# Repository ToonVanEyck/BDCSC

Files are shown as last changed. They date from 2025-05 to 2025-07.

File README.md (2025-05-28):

# Brushed DC Motor Servo Control

The goal of this project is to achieve precise control of a brushed DC motor using sensor less position control based on ripple counting.

# Relevant Application Notes
- [Microchip [AN3049]](https://ww1.microchip.com/downloads/en/AppNotes/Sensorless-Position-Control-of-Brushed-DC-Motor-Using-Ripple-Counting-Technique-00003049A.pdf)
- [TI [TIDA-01421]](https://www.ti.com/lit/ug/tidud30a/tidud30a.pdf?ts=1748200754762)

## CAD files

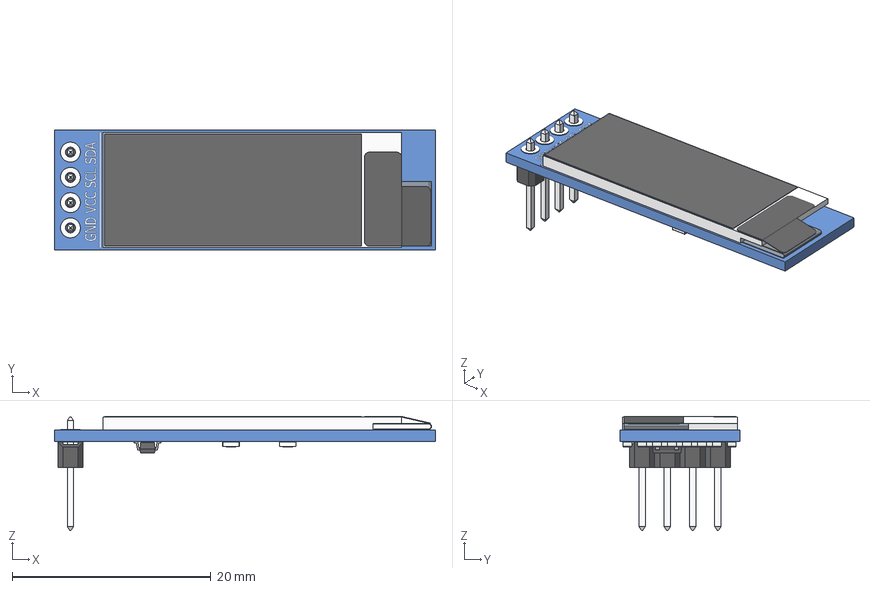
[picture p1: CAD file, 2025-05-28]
hardware/resources/OLED_0.91_128x32.stp
38.3 x 12.1 x 11.5 mm
OLED_0.91_128x32
Pin Header 4 x 1 TH 2.54mm Pitch
RESC-0603 x 13
2SD0601A

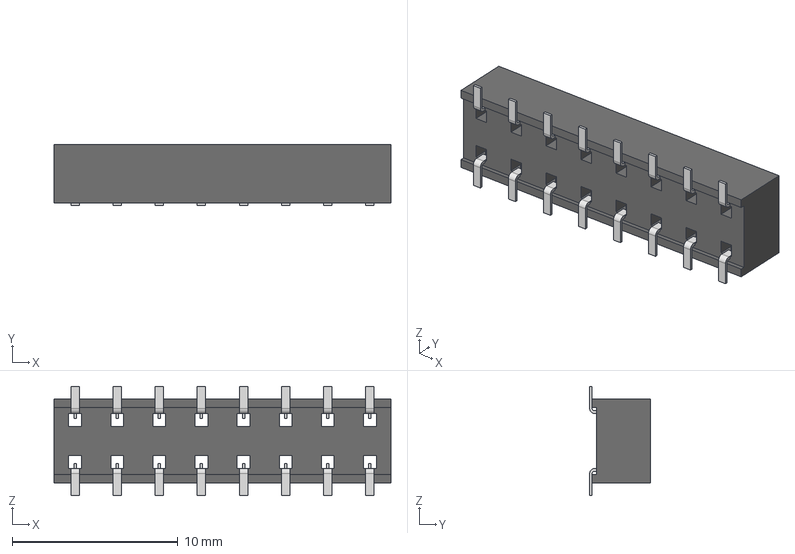
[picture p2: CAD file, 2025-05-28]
hardware/resources/HLE-108-02-L-DV-BE-TR.stp
20.3 x 3.66 x 6.58 mm
HLE-108-02-DV_socket
C-132-12-08-L-DV
C-132-12-08-F-DV2

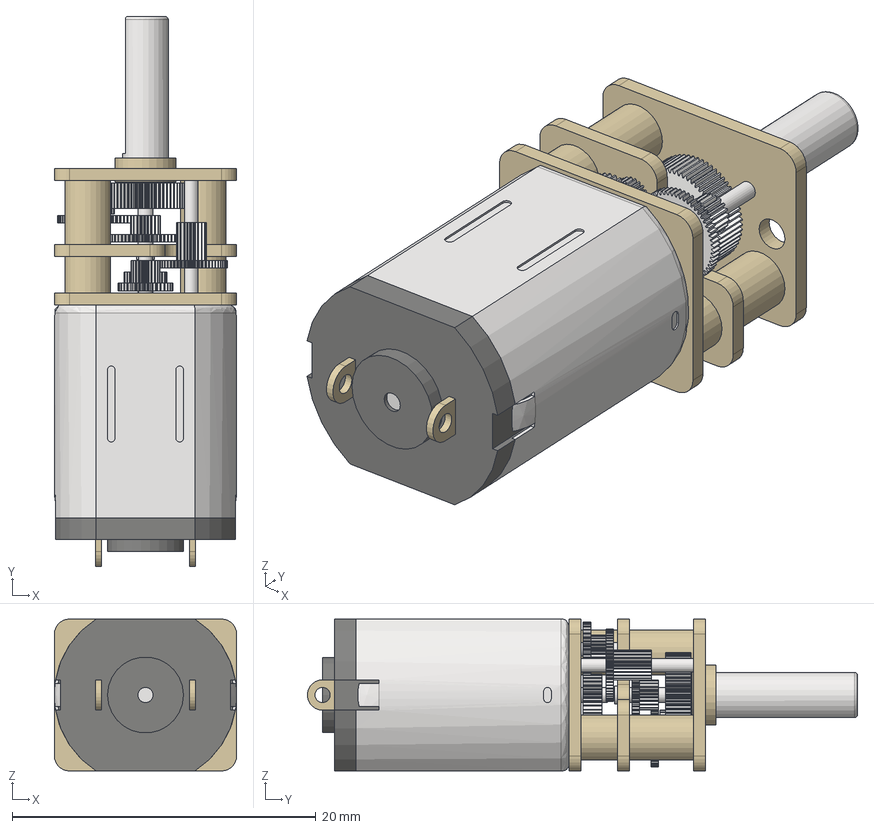
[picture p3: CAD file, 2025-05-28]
hardware/resources/GA12-N20.stp
12.0 x 36.2 x 10.0 mm
Base
Rotor
Apoio Contato
Contato
Suporte Contato
Imãs
Terminais x 2
Escovas
Chapa Inferior
Chapa Intermediária
Chapa Superior
Eixo Maior - Engrenagem
Eixo Menor - Engrenagem
Parafuso x 2
Suporte Bobinas
Eixo Menor - Engrenagem_1
Engrenagem reta1
Engrenagem reta2
Engrenagem reta1_1
Engrenagem reta2_1
Eixo - Encaixe D
Engrenagem reta1_2
Engrenagem reta2_2
Engrenagem reta1_3
Engrenagem reta2_3
Engrenagem reta1_4
Engrenagem reta2_4
Carcaça

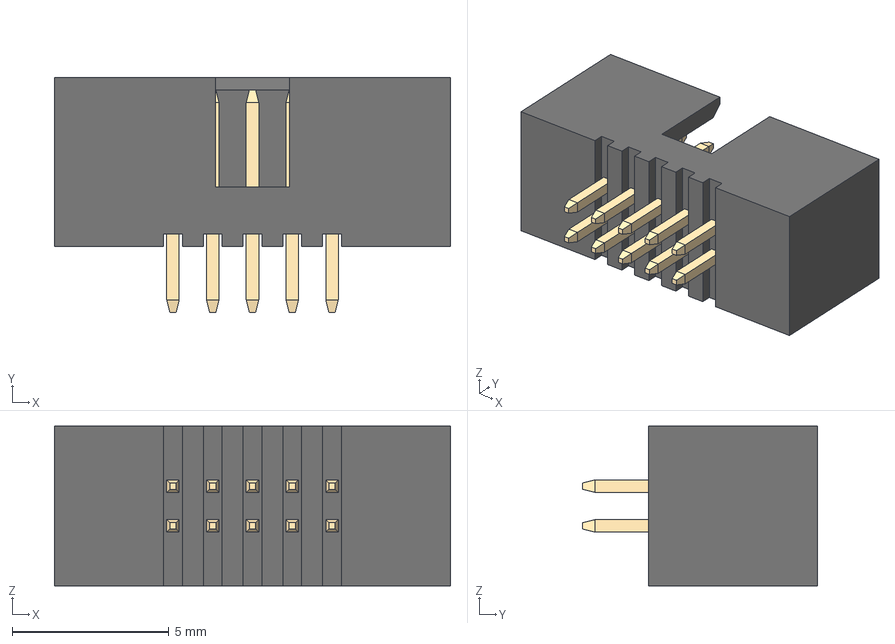
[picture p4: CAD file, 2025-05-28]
hardware/resources/IDC_1.27mm_2x5.stp
12.6 x 7.50 x 5.10 mm

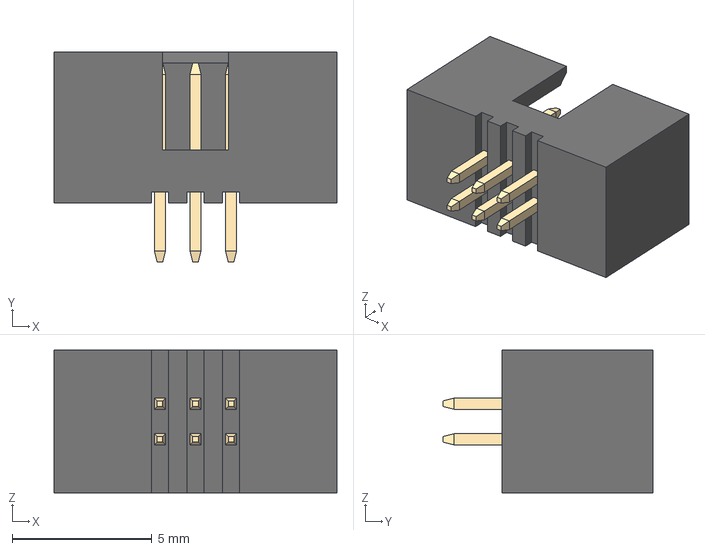
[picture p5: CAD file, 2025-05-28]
hardware/resources/IDC_1.27mm_2x3.stp
10.1 x 7.50 x 5.10 mm

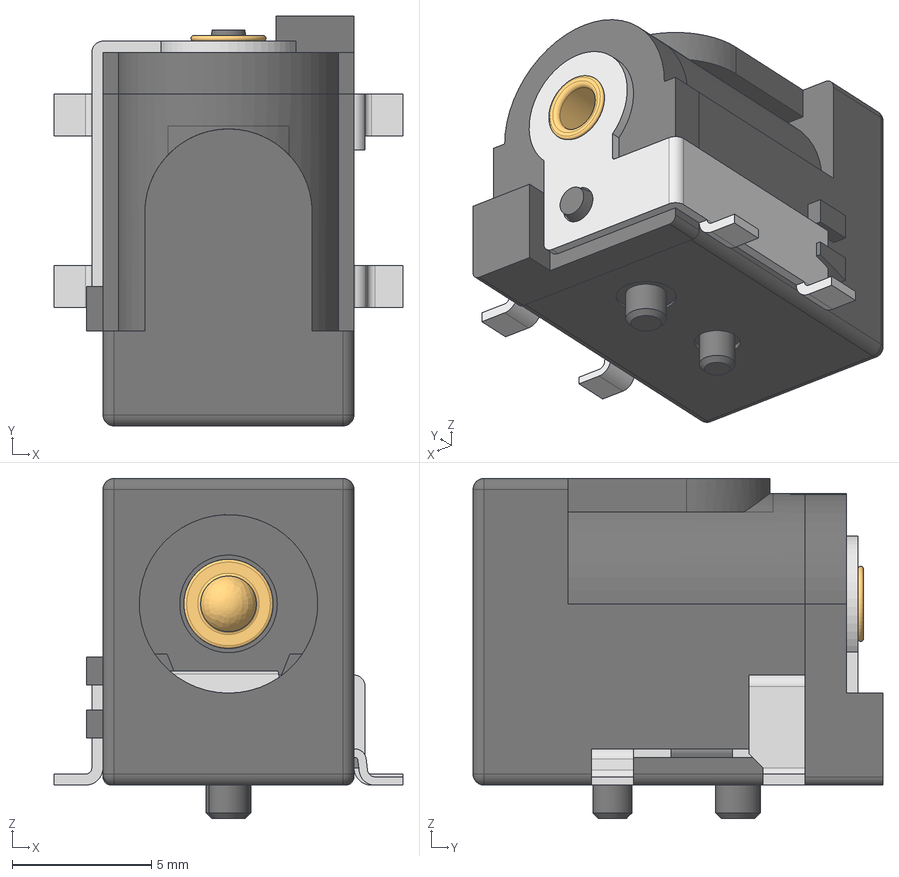
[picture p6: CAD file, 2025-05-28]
hardware/resources/694106106102.stp
12.5 x 14.7 x 12.2 mm
6941xx106102
6941xx106102_Capot
694106301002_PinContact
6941xx106102_PIN
6941xx106102_PINBIS
6941xx106102_PINLAME

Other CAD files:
mechanical/motor_holder.FCStd

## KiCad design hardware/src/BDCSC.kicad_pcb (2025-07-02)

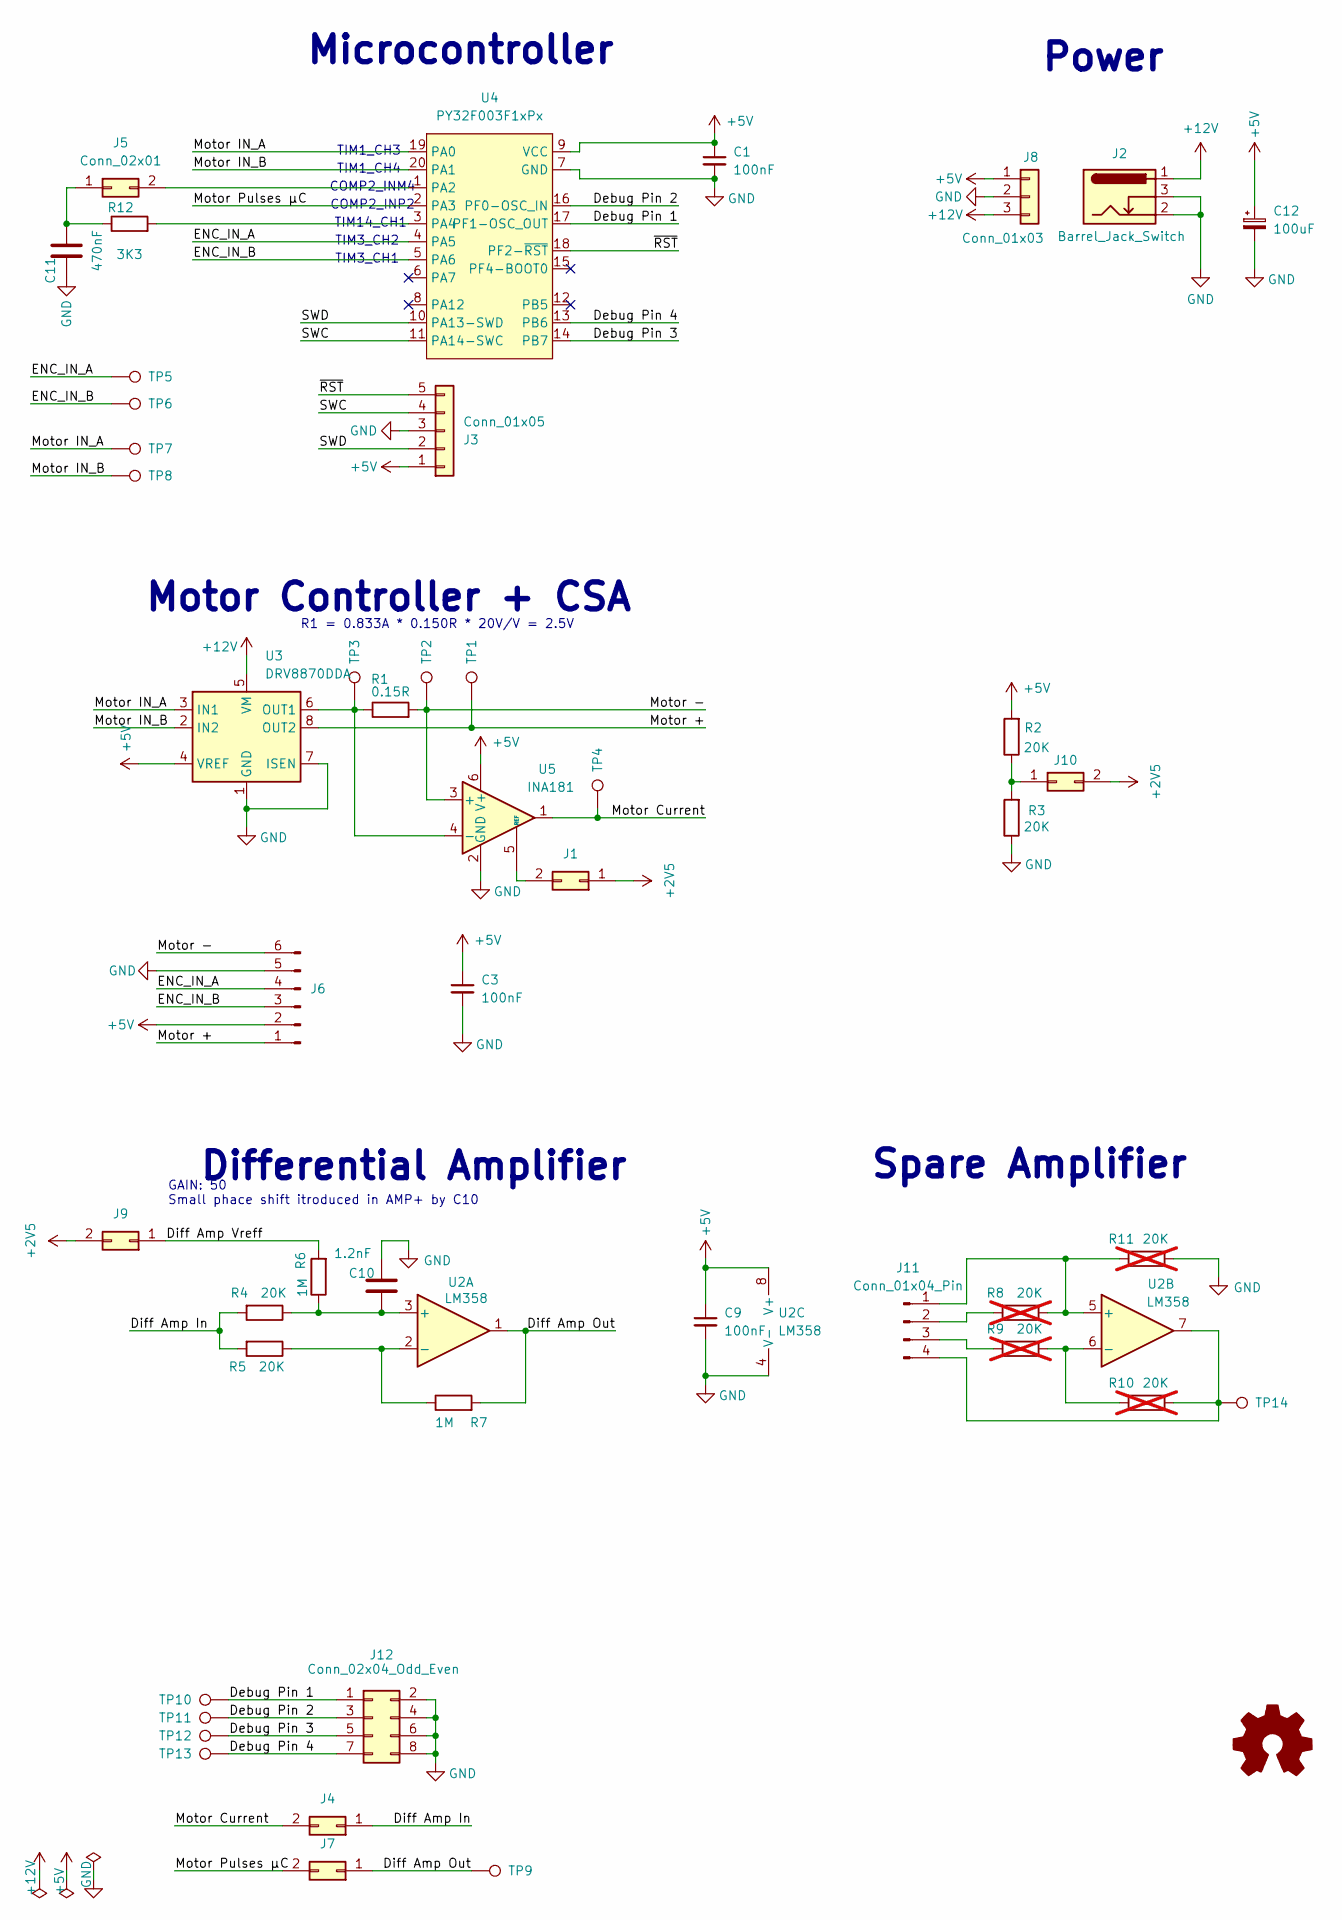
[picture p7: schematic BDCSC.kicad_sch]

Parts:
C1, C3, C9: 100nF; C_0805_2012Metric
C10: 1.2nF; C_0805_2012Metric
C11: 470nF; C_0805_2012Metric
C12: 100uF; CP_EIA-3528-21_Kemet-B; LCSC C16133
J1, J4, J5, J7, J9, J10: Conn_02x01; PinHeader_2x01_P2.54mm_Vertical
J2: Barrel_Jack_Switch; BarrelJack_CLIFF_FC681465S_SMT_Horizontal; LCSC C319133
J3: Conn_01x05; PinHeader_1x05_P2.54mm_Horizontal
J6: Conn_01x06_Pin; PinHeader_1x06_P2.54mm_Horizontal
J8: Conn_01x03; PinHeader_1x03_P2.54mm_Vertical
J11: Conn_01x04_Pin; PinHeader_1x04_P2.54mm_Vertical
J12: Conn_02x04_Odd_Even; PinHeader_2x04_P2.54mm_Vertical
R1: 0.15R; R_1206_3216Metric
R2, R3, R4, R5: 20K; R_0805_2012Metric
R6, R7: 1M; R_0805_2012Metric
R8, R9, R10, R11: 20K; R_0805_2012Metric; not fitted
R12: 3K3; R_0805_2012Metric
TP1, TP2, TP3, TP4, TP5, TP6, TP7, TP8, TP9, TP10, TP11, TP12, TP13, TP14: TestPoint; TestPoint_Keystone_5000-5004_Miniature; LCSC C5277086
U2: LM358; SOIC-8_3.9x4.9mm_P1.27mm
U3: DRV8870DDA; Texas_HTSOP-8-1EP_3.9x4.9mm_P1.27mm_EP2.95x4.9mm_Mask2.4x3.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
U4: PY32F003F1xPx; TSSOP-20_4.4x6.5mm_P0.65mm; LCSC C5379864
U5: INA181; SOT-23-6

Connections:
+2V5: J1.1, J9.2, J10.2
+5V: C1.1, C3.1, C9.1, C12.1, J3.1, J6.2, J8.1, R2.2, U2.8 (V+), U3.4 (VREF), U4.9 (VCC), U5.6 (V+)
+12V: J2.1, J8.3, U3.5 (VM)
/Debug Pin 1: J12.1, TP10.1, U4.17 (PF1-OSC_OUT)
/Debug Pin 2: J12.3, TP11.1, U4.16 (PF0-OSC_IN)
/Debug Pin 3: J12.5, TP12.1, U4.14 (PB7)
/Debug Pin 4: J12.7, TP13.1, U4.13 (PB6)
/Diff Amp In: J4.1, R4.2, R5.2
/Diff Amp Out: J7.1, R7.2, TP9.1, U2.1
/Diff Amp Vreff: J9.1, R6.2
/ENC_IN_A: J6.4, TP5.1, U4.4 (PA5)
/ENC_IN_B: J6.3, TP6.1, U4.5 (PA6)
/Motor +: J6.1, TP1.1, U3.8 (OUT2)
/Motor -: J6.6, R1.2, TP2.1, U5.3 (+)
/Motor Current: J4.2, TP4.1, U5.1
/Motor IN_A: TP7.1, U3.3 (IN1), U4.19 (PA0)
/Motor IN_B: TP8.1, U3.2 (IN2), U4.20 (PA1)
/Motor Pulses µC: J7.2, U4.2 (PA3)
/SWC: J3.4, U4.11 (PA14-SWC)
/SWD: J3.2, U4.10 (PA13-SWD)
/~RST: J3.5, U4.18 (PF2-~RST)
GND: C1.2, C3.2, C9.2, C10.2, C11.1, C12.2, J2.2, J2.3, J3.3, J6.5, J8.2, J12.2, J12.4, J12.6, J12.8, R3.1, R11.1, U2.4 (V-), U3.1 (GND), U3.7 (ISEN), U3.9 (GND), U4.7 (GND), U5.2 (GND)
unnamed: J1.2, U5.5 (REF)
unnamed: C11.2, J5.1, R12.1
unnamed: J5.2, U4.1 (PA2)
unnamed: J10.1, R2.1, R3.2
unnamed: J11.1, R8.1, R11.2, U2.5 (+)
unnamed: J11.2, R8.2
unnamed: J11.3, R9.2
unnamed: J11.4, R10.1, TP14.1, U2.7
unnamed: C10.1, R4.1, R6.1, U2.3 (+)
unnamed: R5.1, R7.1, U2.2 (-)
unnamed: R9.1, R10.2, U2.6 (-)
unnamed: R1.1, TP3.1, U3.6 (OUT1), U5.4 (-)
unnamed: R12.2, U4.3 (PA4)

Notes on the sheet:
Differential Amplifier
GAIN: 50 Small phace shift itroduced in AMP+ by C10
Motor Controller + CSA
TIM3_CH1
Spare Amplifier
Microcontroller
TIM3_CH2
Power
COMP2_INM4
TIM1_CH4
COMP2_INP2
TIM1_CH3
R1 = 0.833A * 0.150R * 20V/V = 2.5V
TIM14_CH1

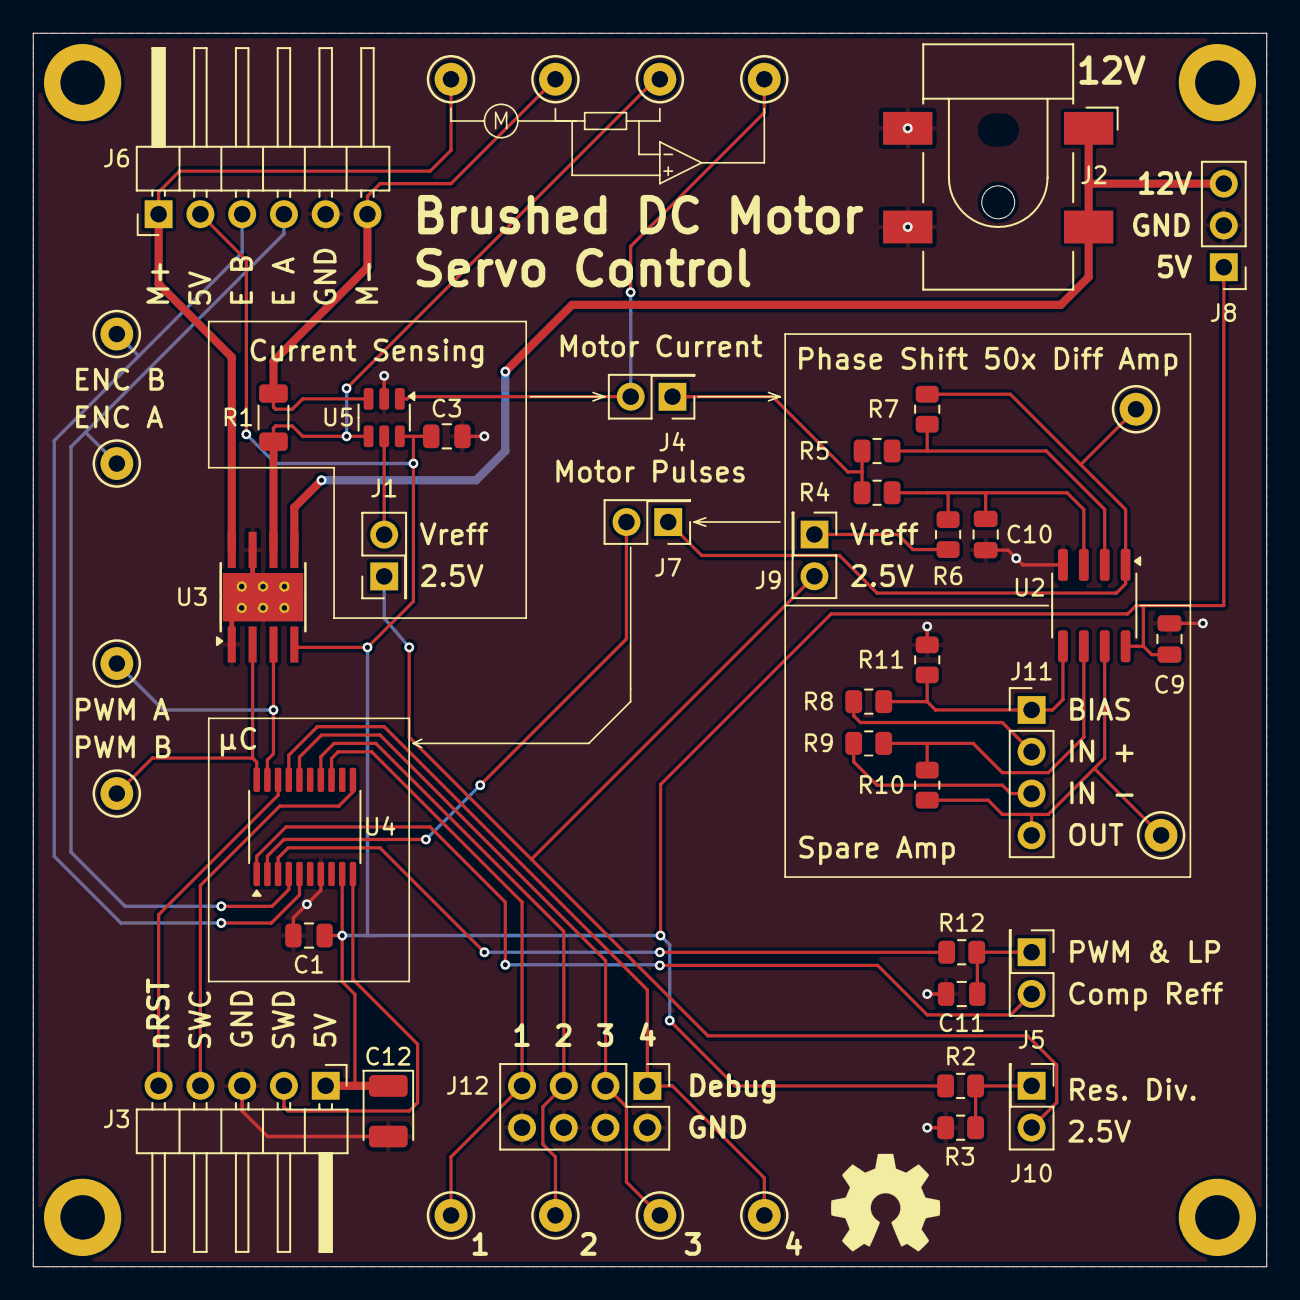
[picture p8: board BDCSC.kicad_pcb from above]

Board: 2 copper layers, 75.0 x 75.0 mm, 48 parts (0 on the bottom side), 35 nets.

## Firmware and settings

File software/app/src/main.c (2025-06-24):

/* Includes ------------------------------------------------------------------*/
#include "bdcsc.h"

/* Private define ------------------------------------------------------------*/

#ifndef VERSION
#define VERSION "not found"
#endif

#define MOTOR_GEAR_RATIO                       (298)
#define MOTOR_ENCODER_PULSES_PER_REVOLUTION    (7 * 4)
#define MOTOR_SENSORLESS_PULSES_PER_REVOLUTION (6)

/* Private variables ---------------------------------------------------------*/
ADC_HandleTypeDef AdcHandle;
ADC_ChannelConfTypeDef sConfig;
uint32_t aADCxConvertedData[ENCODER_CHANNEL_CNT] = {0};

TIM_HandleTypeDef Tim1Handle;     // ADC/IR timer
TIM_HandleTypeDef encoderHandle;  // Encoder timer
TIM_HandleTypeDef motorPwmHandle; // PWM

typedef struct {
    bool enable;       /**< Enable motor. */
    uint8_t speed;     /**< Motor speed (0-255). */
    bool direction_cw; /**< Motor direction: true for clockwise, false for counter-clockwise. */
} motor_t;

/* Private macro -------------------------------------------------------------*/

/* Private function prototypes -----------------------------------------------*/
void APP_ErrorHandler(void);
static void APP_GpioConfig(void);
static void APP_TimerInit(void);
static void APP_PwmInit(void);
static void APP_AdcConfig(void);
static void APP_DmaInit(void);
static void APP_EncoderInit(void);

void motor_update(const motor_t *motor);

uint16_t encoder_position_get(void);

/* Debug terminal functions. */
void debug_term_motor_toggle(const char *input, void *arg);
void debug_term_motor_set_speed(const char *input, void *arg);
void debug_term_motor_position_set(const char *input, void *arg);
void debug_term_motor_set_direction(const char *input, void *arg);
void debug_term_encoder_toggle(const char *input, void *arg);
void debug_term_pid_set(const char *input, void *arg);
void debug_term_pid_print(const char *input, void *arg);
/* Motor stuff */
static motor_t debug_motor           = {0};
static uint16_t debug_motor_position = 0; /**< Current motor position. */

/* Debug GPIO */
static bool debug_gpio[4] = {false, false, false, false};

/* Quad encoder */
static uint16_t prev_encoder_value = 0;
static bool enable_encoder         = false;

/* PID */
pid_ctx_t pid_ctx = {0};

/* Debug IO scope struct */
typedef struct {
    uint32_t setpoint;
    uint32_t actual;
    int32_t p;
    int32_t i;
    int32_t d;
    int32_t error;
} debug_io_scope_t;
static debug_io_scope_t debug_io_scope = {0};

int main(void)
{
    HAL_Init();
    BSP_HSI_24MHzClockConfig();

    debug_io_init(LOG_LVL_DEBUG);
    debug_io_scope_init("u4u4i4i4i4i4");

    APP_GpioConfig();
    // APP_DmaInit();
    // APP_AdcConfig();
    APP_PwmInit();
    APP_EncoderInit();
    motor_update(&debug_motor);
    // APP_TimerInit();

    debug_io_term_register_keyword("m", debug_term_motor_toggle, &debug_motor);
    debug_io_term_register_keyword("ms", debug_term_motor_set_speed, &debug_motor);
    debug_io_term_register_keyword("md", debug_term_motor_set_direction, &debug_motor);
    debug_io_term_register_keyword("mp", debug_term_motor_position_set, &debug_motor);
    debug_io_term_register_keyword("enc", debug_term_encoder_toggle, NULL);
    debug_io_term_register_keyword("pid", debug_term_pid_set, &pid_ctx);
    debug_io_term_register_keyword("pe", debug_term_pid_print, &pid_ctx); /* Register the new function */

    debug_io_log_info("BDCSC dev board\n");
    debug_io_log_info("Version: %s\n", GIT_VERSION);
    debug_io_log_info("Compilation Date: %s %s\n", __DATE__, __TIME__);

    pid_init(&pid_ctx, 3000, 300, -800); // Initialize PID with kp=1, ki=0, kd=0
    while (1) {

        debug_io_term_process();
        uint16_t encoder_count = encoder_position_get();
        if (encoder_count != prev_encoder_value) {
            prev_encoder_value = encoder_count;
            if (enable_encoder) {
                debug_io_log_info("ENC: %u\n", encoder_count);
            }
        }

        static uint32_t last_tick = 0;
        uint32_t current_tick     = HAL_GetTick();
        if (current_tick - last_tick >= 50) { // every 10 ms
            last_tick = current_tick;
            if (debug_motor.enable) {
                pid_ctx.setpoint   = debug_motor_position / 6;
                int16_t pid_output = pid_compute(&pid_ctx, encoder_count / 6);
                if (pid_output > 0) {
                    debug_motor.direction_cw = true;
                    debug_motor.speed        = (uint8_t)(pid_output > 255 ? 255 : pid_output);
                } else {
                    debug_motor.direction_cw = false;
                    debug_motor.speed        = (uint8_t)(-pid_output > 255 ? 255 : -pid_output);
                }
                if (debug_motor.speed < 10) {
                    debug_motor.speed = 0; // If speed is too low, stop the motor
                }
                if (encoder_count != prev_encoder_value) {
                    prev_encoder_value = encoder_count;
                    // debug_io_log_info("PID: %d, Speed: %u, Position: %u\n", pid_output, debug_motor.speed,
                    //                   encoder_count);
                }
                motor_update(&debug_motor);
            }
            // debug_io_log_debug("Hello World!\n");
            debug_io_scope.setpoint = pid_ctx.setpoint;
            debug_io_scope.actual   = encoder_count / 6;
            debug_io_scope.p        = pid_ctx.p_error;
            debug_io_scope.i        = pid_ctx.i_error;
            debug_io_scope.d        = pid_ctx.d_error;
            debug_io_scope.error    = pid_ctx.output;

            debug_io_scope_push(&debug_io_scope, sizeof(debug_io_scope));
        }
    }
}

static void APP_GpioConfig(void)
{
    GPIO_InitTypeDef GPIO_InitStruct;

    __HAL_RCC_GPIOB_CLK_ENABLE();
    __HAL_RCC_GPIOA_CLK_ENABLE();
    __HAL_RCC_GPIOF_CLK_ENABLE();

    // /* Configure column-end detection pin. */
    // GPIO_InitStruct.Pin   = COLEND_GPIO_PIN;
    // GPIO_InitStruct.Mode  = GPIO_MODE_INPUT;
    // GPIO_InitStruct.Pull  = GPIO_PULLUP;
    // GPIO_InitStruct.Speed = GPIO_SPEED_FREQ_HIGH;
    // HAL_GPIO_Init(COLEND_GPIO_PORT, &GPIO_InitStruct);

    // /* Configure IR LED */
    // GPIO_InitStruct.Pin   = ENCODER_LED_GPIO_PIN;
    // GPIO_InitStruct.Mode  = GPIO_MODE_OUTPUT_PP;
    // GPIO_InitStruct.Pull  = GPIO_PULLUP;
    // GPIO_InitStruct.Speed = GPIO_SPEED_FREQ_HIGH;
    // HAL_GPIO_Init(ENCODER_LED_GPIO_PORT, &GPIO_InitStruct);

    /* Configure debug pins, these pins can be used for pin wiggling during development. */
    GPIO_InitStruct.Pin   = DEBUG_GPIO_1_PIN | DEBUG_GPIO_2_PIN;
    GPIO_InitStruct.Mode  = GPIO_MODE_OUTPUT_PP;
    GPIO_InitStruct.Pull  = GPIO_PULLUP;
    GPIO_InitStruct.Speed = GPIO_SPEED_FREQ_HIGH;
    HAL_GPIO_Init(DEBUG_GPIO_1_2_PORT, &GPIO_InitStruct);

    GPIO_InitStruct.Pin   = DEBUG_GPIO_3_PIN | DEBUG_GPIO_4_PIN;
    GPIO_InitStruct.Mode  = GPIO_MODE_OUTPUT_PP;
    GPIO_InitStruct.Pull  = GPIO_PULLUP;
    GPIO_InitStruct.Speed = GPIO_SPEED_FREQ_HIGH;
    HAL_GPIO_Init(DEBUG_GPIO_3_4_PORT, &GPIO_InitStruct);
}

static void APP_AdcConfig(void)
{
    __HAL_RCC_ADC_FORCE_RESET();
    __HAL_RCC_ADC_RELEASE_RESET(); /* Reset ADC */
    __HAL_RCC_ADC_CLK_ENABLE();    /* Enable ADC clock */

    AdcHandle.Instance = ADC1;
    if (HAL_ADCEx_Calibration_Start(&AdcHandle) != HAL_OK) {
        APP_ErrorHandler();
    }
    AdcHandle.Init.ClockPrescaler        = ADC_CLOCK_SYNC_PCLK_DIV1;   /* ADC clock no division */
    AdcHandle.Init.Resolution            = ADC_RESOLUTION_10B;         /* 12bit */
    AdcHandle.Init.DataAlign             = ADC_DATAALIGN_RIGHT;        /* Right alignment */
    AdcHandle.Init.ScanConvMode          = ADC_SCAN_DIRECTION_FORWARD; /* Forward */
    AdcHandle.Init.EOCSelection          = ADC_EOC_SEQ_CONV;           /* End flag */
    AdcHandle.Init.LowPowerAutoWait      = ENABLE;
    AdcHandle.Init.ContinuousConvMode    = DISABLE;
    AdcHandle.Init.DiscontinuousConvMode = DISABLE;
    AdcHandle.Init.ExternalTrigConv      = ADC1_2_EXTERNALTRIG_T1_TRGO; /* External trigger: TIM1_TRGO */
    AdcHandle.Init.ExternalTrigConvEdge  = ADC_EXTERNALTRIGCONVEDGE_NONE;
    AdcHandle.Init.DMAContinuousRequests = ENABLE; /* DMA */
    AdcHandle.Init.Overrun               = ADC_OVR_DATA_OVERWRITTEN;
    AdcHandle.Init.SamplingTimeCommon    = ADC_SAMPLETIME_41CYCLES_5;
    if (HAL_ADC_Init(&AdcHandle) != HAL_OK) {
        APP_ErrorHandler();
    }

    sConfig.Rank = ADC_RANK_CHANNEL_NUMBER;
    /* Configure the ADC channels. */
    for (uint8_t i = 0; i < ENCODER_CHANNEL_CNT; i++) {
        sConfig.Channel = ENCODER_ADC_CHANNEL_LIST[i];
        if (HAL_ADC_ConfigChannel(&AdcHandle, &sConfig) != HAL_OK) {
            APP_ErrorHandler();
        }
    }
}

static void APP_TimerInit(void)
{
    // /* (240 * 10) / 24Mhz = 100us */
    // Tim1Handle.Instance               = TIM1;
    // Tim1Handle.Init.Period            = 10 - 1;
    // Tim1Handle.Init.Prescaler         = 240 - 1;
    // Tim1Handle.Init.ClockDivision     = TIM_CLOCKDIVISION_DIV1;
    // Tim1Handle.Init.CounterMode       = TIM_COUNTERMODE_UP;
    // Tim1Handle.Init.RepetitionCounter = 0;
    // Tim1Handle.Init.AutoReloadPreload = TIM_AUTORELOAD_PRELOAD_DISABLE;
    // if (HAL_TIM_Base_Init(&Tim1Handle) != HAL_OK) {
    //     APP_ErrorHandler();
    // }

    // TIM_MasterConfigTypeDef sMasterConfig;
    // sMasterConfig.MasterOutputTrigger = TIM_TRGO_UPDATE;
    // sMasterConfig.MasterSlaveMode     = TIM_MASTERSLAVEMODE_DISABLE;
    // HAL_TIMEx_MasterConfigSynchronization(&Tim1Handle, &sMasterConfig);
    // if (HAL_TIM_Base_Start_IT(&Tim1Handle) != HAL_OK) {
    //     APP_ErrorHandler();
    // }
}

static void APP_PwmInit(void)
{
    /* 24MHz / ( 255 x 466 x 2 ) = +/- 200Hz */
    motorPwmHandle.Instance           = TIM1;
    motorPwmHandle.Init.Period        = 255 - 1;
    motorPwmHandle.Init.Prescaler     = 470 - 1;
    motorPwmHandle.Init.ClockDivision = TIM_CLOCKDIVISION_DIV2;
    motorPwmHandle.Init.CounterMode   = TIM_COUNTERMODE_UP;
    // motorPwmHandle.Init.RepetitionCounter = 0;
    // motorPwmHandle.Init.AutoReloadPreload = TIM_AUTORELOAD_PRELOAD_DISABLE;
    if (HAL_TIM_PWM_Init(&motorPwmHandle) != HAL_OK) {
        APP_ErrorHandler();
    }

    TIM_MasterConfigTypeDef sMasterConfig;
    sMasterConfig.MasterOutputTrigger = TIM_TRGO_RESET;
    sMasterConfig.MasterSlaveMode     = TIM_MASTERSLAVEMODE_DISABLE;
    HAL_TIMEx_MasterConfigSynchronization(&motorPwmHandle, &sMasterConfig);

    TIM_OC_InitTypeDef sConfigOC;
    sConfigOC.OCMode     = TIM_OCMODE_PWM1;
    sConfigOC.Pulse      = 0;
    sConfigOC.OCPolarity = TIM_OCPOLARITY_HIGH;
    sConfigOC.OCFastMode = TIM_OCFAST_DISABLE;

    // Configure channel 1
    HAL_TIM_PWM_ConfigChannel(&motorPwmHandle, &sConfigOC, TIM_CHANNEL_3);
    HAL_TIM_PWM_Start(&motorPwmHandle, TIM_CHANNEL_3);

    // Configure channel 2
    HAL_TIM_PWM_ConfigChannel(&motorPwmHandle, &sConfigOC, TIM_CHANNEL_4);
    HAL_TIM_PWM_Start(&motorPwmHandle, TIM_CHANNEL_4);
}

void APP_EncoderInit(void)
{
    encoderHandle.Instance               = TIM3;
    encoderHandle.Init.Prescaler         = 0;
    encoderHandle.Init.CounterMode       = TIM_COUNTERMODE_UP;
    encoderHandle.Init.Period            = 298 * 7 * 4 - 1; /* 298*7*4 = 8344, so period is 8343 */
    encoderHandle.Init.ClockDivision     = TIM_CLOCKDIVISION_DIV1;
    encoderHandle.Init.RepetitionCounter = 0;
    encoderHandle.Init.AutoReloadPreload = TIM_AUTORELOAD_PRELOAD_DISABLE;

    TIM_Encoder_InitTypeDef sConfig = {0};
    sConfig.EncoderMode             = TIM_ENCODERMODE_TI12;
    sConfig.IC1Polarity             = TIM_ICPOLARITY_RISING;
    sConfig.IC1Selection            = TIM_ICSELECTION_DIRECTTI;
    sConfig.IC1Prescaler            = TIM_ICPSC_DIV1;
    sConfig.IC1Filter               = 10;
    sConfig.IC2Polarity             = TIM_ICPOLARITY_RISING;
    sConfig.IC2Selection            = TIM_ICSELECTION_DIRECTTI;
    sConfig.IC2Prescaler            = TIM_ICPSC_DIV1;
    sConfig.IC2Filter               = 10;

    if (HAL_TIM_Encoder_Init(&encoderHandle, &sConfig) != HAL_OK) {
        APP_ErrorHandler();
    }

    HAL_TIM_Encoder_Start(&encoderHandle, TIM_CHANNEL_ALL);
}

static void APP_DmaInit(void)
{
    HAL_NVIC_SetPriority(DMA1_Channel1_IRQn, 3, 0);
    HAL_NVIC_EnableIRQ(DMA1_Channel1_IRQn);
}

void HAL_ADC_ConvCpltCallback(ADC_HandleTypeDef *hadc)
{
    /* Disable IR led. */
    // HAL_GPIO_WritePin(ENCODER_LED_GPIO_PORT, ENCODER_LED_GPIO_PIN, GPIO_PIN_RESET);

    if (false) {
        debug_io_log_debug("ABZ: %04ld %04ld %04ld\n", aADCxConvertedData[ENCODER_CHANNEL_A],
                           aADCxConvertedData[ENCODER_CHANNEL_B], aADCxConvertedData[ENCODER_CHANNEL_Z]);
    }
}

void HAL_TIM_PeriodElapsedCallback(TIM_HandleTypeDef *htim)
{
    if (htim->Instance == TIM1) {
    }
}

void APP_ErrorHandler(void)
{
    while (1)
        ;
}

void motor_update(const motor_t *motor)
{
    if (motor->enable) {
        if (motor->direction_cw) {
            __HAL_TIM_SET_COMPARE(&motorPwmHandle, TIM_CHANNEL_3, 0xff - motor->speed);
            __HAL_TIM_SET_COMPARE(&motorPwmHandle, TIM_CHANNEL_4, 0xff);
        } else {
            __HAL_TIM_SET_COMPARE(&motorPwmHandle, TIM_CHANNEL_3, 0xff);
            __HAL_TIM_SET_COMPARE(&motorPwmHandle, TIM_CHANNEL_4, 0xff - motor->speed);
        }
    } else {
        __HAL_TIM_SET_COMPARE(&motorPwmHandle, TIM_CHANNEL_3, 0);
        __HAL_TIM_SET_COMPARE(&motorPwmHandle, TIM_CHANNEL_4, 0);
    }
}

/**
 * \brief Get the current encoder position.
 *
 * The encoder position is scaled to match the encoder position as it would be measured with the sensorless method.
 */
uint16_t encoder_position_get(void)
{
    return __HAL_TIM_GET_COUNTER(&encoderHandle) * MOTOR_SENSORLESS_PULSES_PER_REVOLUTION /
           MOTOR_ENCODER_PULSES_PER_REVOLUTION;
}

void debug_term_motor_toggle(const char *input, void *arg)
{
    motor_t *motor = (motor_t *)arg;
    motor->enable  = !motor->enable;
    debug_io_log_info("Motor: %s\n", motor->enable ? "enabled" : "disabled");
    motor_update(motor);
}

void debug_term_motor_set_speed(const char *input, void *arg)
{
    motor_t *motor = (motor_t *)arg;
    int speed      = atoi(input);
    if (speed < 0 || speed > 255) {
        debug_io_log_info("Invalid speed value. Must be between 0 and 255.\n");
        return;
    }
    motor->speed = (uint8_t)speed;
    debug_io_log_info("Motor speed set to: %u\n", motor->speed);
    motor_update(motor);
}

void debug_term_motor_set_direction(const char *input, void *arg)
{
    motor_t *motor = (motor_t *)arg;
    if (strcmp(input, "cw") == 0) {
        motor->direction_cw = true;
        debug_io_log_info("Motor direction set to: CW\n");
    } else if (strcmp(input, "ccw") == 0) {
        motor->direction_cw = false;
        debug_io_log_info("Motor direction set to: CCW\n");
    } else {
        debug_io_log_info("Invalid direction. Use 'cw' or 'ccw'.\n");
    }
    motor_update(motor);
}

void debug_term_motor_position_set(const char *input, void *arg)
{
    motor_t *motor = (motor_t *)arg;
    int position   = atoi(input);
    if (position < 0 || position > 1787) {
        debug_io_log_info("Invalid position value. Must be between 0 and 1787.\n");
        return;
    }
    debug_motor_position = (uint16_t)position;
    debug_io_log_info("Motor position set to: %u\n", debug_motor_position);
}

void debug_term_encoder_toggle(const char *input, void *arg)
{
    enable_encoder = !enable_encoder;
    debug_io_log_info("Encoder: %s\n", enable_encoder ? "enabled" : "disabled");
}

void debug_term_pid_set(const char *input, void *arg)
{
    pid_ctx_t *pid = (pid_ctx_t *)arg;
    int kp, ki, kd;
    if (sscanf(input, "%d %d %d", &kp, &ki, &kd) == 3) {
        pid->kp = kp;
        pid->ki = ki;
        pid->kd = kd;
        debug_io_log_info("PID gains set: kp=%d, ki=%d, kd=%d\n", kp, ki, kd);
    } else {
        debug_io_log_info("Usage: pid <kp> <ki> <kd>\n");
    }
}

void debug_term_pid_print(const char *input, void *arg)
{
    pid_ctx_t *pid = (pid_ctx_t *)arg;

    // Print all internal PID values for debugging
    debug_io_log_info("PID Internal State:\n");
    debug_io_log_info("  Gains: kp=%d, ki=%d, kd=%d\n", pid->kp, pid->ki, pid->kd);
    debug_io_log_info("  Setpoint: %d, Current Input: %d\n", pid->setpoint, encoder_position_get() / 6);
    debug_io_log_info("  Error: %d\n", pid->setpoint - (encoder_position_get() / 6));
    debug_io_log_info("  P-term: %d\n", pid->p_error);
    debug_io_log_info("  I-term: %d\n", pid->i_error);
    debug_io_log_info("  D-term: %d\n", pid->d_error);
    debug_io_log_info("  Output: %d\n", pid->output);
}

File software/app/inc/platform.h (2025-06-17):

#pragma once

#include <stdbool.h>
#include <stdint.h>
#include <string.h>

#include "debug_io.h"
#include "py32f0xx_bsp_clock.h"
#include "py32f0xx_hal.h"

/**
 * \defgroup Column-end detection pin definitions.
 * @{
 */
#define COLEND_GPIO_PIN  GPIO_PIN_1
#define COLEND_GPIO_PORT GPIOA
/**
 * @}
 */

/**
 * \defgroup Absolute encoder IR definitions.
 * @{
 */
#define ENCODER_CHANNEL_CNT (3) /**< Number of tracks on the encoder. */

#define ENCODER_CHANNEL_A (0) /**< Encoder Channel A. */
#define ENCODER_CHANNEL_B (2) /**< Encoder Channel B. */
#define ENCODER_CHANNEL_Z (1) /**< Encoder Channel Z. */

/** List of ADC channels used by the encoder. */
#define ENCODER_ADC_CHANNEL_LIST                                                                                       \
    ((uint32_t[ENCODER_CHANNEL_CNT]) {                                                                                 \
        ADC_CHANNEL_3,                                                                                                 \
        ADC_CHANNEL_4,                                                                                                 \
        ADC_CHANNEL_5,                                                                                                 \
    })

#define ENCODER_ADC_GPIO_PINS (GPIO_PIN_3 | GPIO_PIN_4 | GPIO_PIN_5) /**< The pins used for ADC by the encoder. */
#define ENCODER_ADC_GPIO_PORT (GPIOA)                                /**< ADC port. */
#define ENCODER_LED_GPIO_PIN  (GPIO_PIN_2) /**< Single pin driving the IR emitters of the IR sensors. */
#define ENCODER_LED_GPIO_PORT (GPIOA)      /**< IR emitter GPIO port. */
/**
 * @}
 */

/**
 * \defgroup Motor pin definitions.
 * @{
 */
#define MOTOR_GPIO_PORT (GPIOA)                   /**< Motor GPIO port. */
#define MOTOR_GPIO_PINS (GPIO_PIN_0 | GPIO_PIN_1) /**< Motor GPIO pins. */
/**
 * @}
 */

/**
 * \defgroup UART pin definitions.
 * @{
 */
#define UART_TX_GPIO_PIN (GPIO_PIN_6) /**< UART TX Pin. */
#define UART_RX_GPIO_PIN (GPIO_PIN_7) /**< UART RX Pin. */
#define UART_GPIO_PORT   (GPIOB)      /**< UART Port. */
/**
 * @}
 */

/**
 * \defgroup DEBUG pin definitions.
 * @{
 */
#define DEBUG_GPIO_1_PIN    (GPIO_PIN_1) /**< DEBUG 1 Pin. */
#define DEBUG_GPIO_2_PIN    (GPIO_PIN_0) /**< DEBUG 2 Pin. */
#define DEBUG_GPIO_3_PIN    (GPIO_PIN_6) /**< DEBUG 3 Pin. */
#define DEBUG_GPIO_4_PIN    (GPIO_PIN_7) /**< DEBUG 6 Pin. */
#define DEBUG_GPIO_1_2_PORT (GPIOF)      /**< DEBUG Port. */
#define DEBUG_GPIO_3_4_PORT (GPIOB)      /**< DEBUG Port. */

/**
 * @}
 */

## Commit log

2025-06-17 cleanup in preparation for hardware
    [BDCSC.kicad_pcb, BDCSC.kicad_sch]
2025-06-20 Start om crude RTT scope for proper pid tuning and validation
2025-06-24 added web based rtt viewer for pid tuning
    [motor_holder.FCStd]
2025-07-02 Updated dev board and cad model
    [BDCSC.kicad_pcb, BDCSC.kicad_sch, motor_holder.FCStd]

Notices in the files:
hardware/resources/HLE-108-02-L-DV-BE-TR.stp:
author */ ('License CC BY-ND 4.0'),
